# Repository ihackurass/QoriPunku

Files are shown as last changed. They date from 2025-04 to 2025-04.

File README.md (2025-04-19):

# QoriPunku (SecureGate)


[]()

## Visión General

**QoriPunku** ("Puerta de Oro" en quechua) es un sistema de control de acceso inteligente que combina tecnología RFID con verificación remota mediante fotografías. Diseñado para mejorar la seguridad en puntos de acceso, permite la autenticación rápida de usuarios registrados y ofrece una segunda capa de verificación por administrador para visitantes no registrados.

## Características Principales

- **Autenticación RFID**: Identificación rápida mediante tarjetas autorizadas
- **Sistema de respaldo fotográfico**: Captura imágenes de visitantes no autorizados
- **Verificación remota**: Envío de fotografías al administrador vía WhatsApp
- **Control de acceso dual**: RFID para usuarios regulares, aprobación administrativa para visitantes
- **Panel administrativo**: Configuración de parámetros del sistema mediante contraseña
- **Acceso automático**: Apertura de puerta mediante servomotor

## Componentes de Hardware

<div align="center">
  
  
  
  
  
  
  
  
</div>

## Diagrama del Sistema

<div align="center">
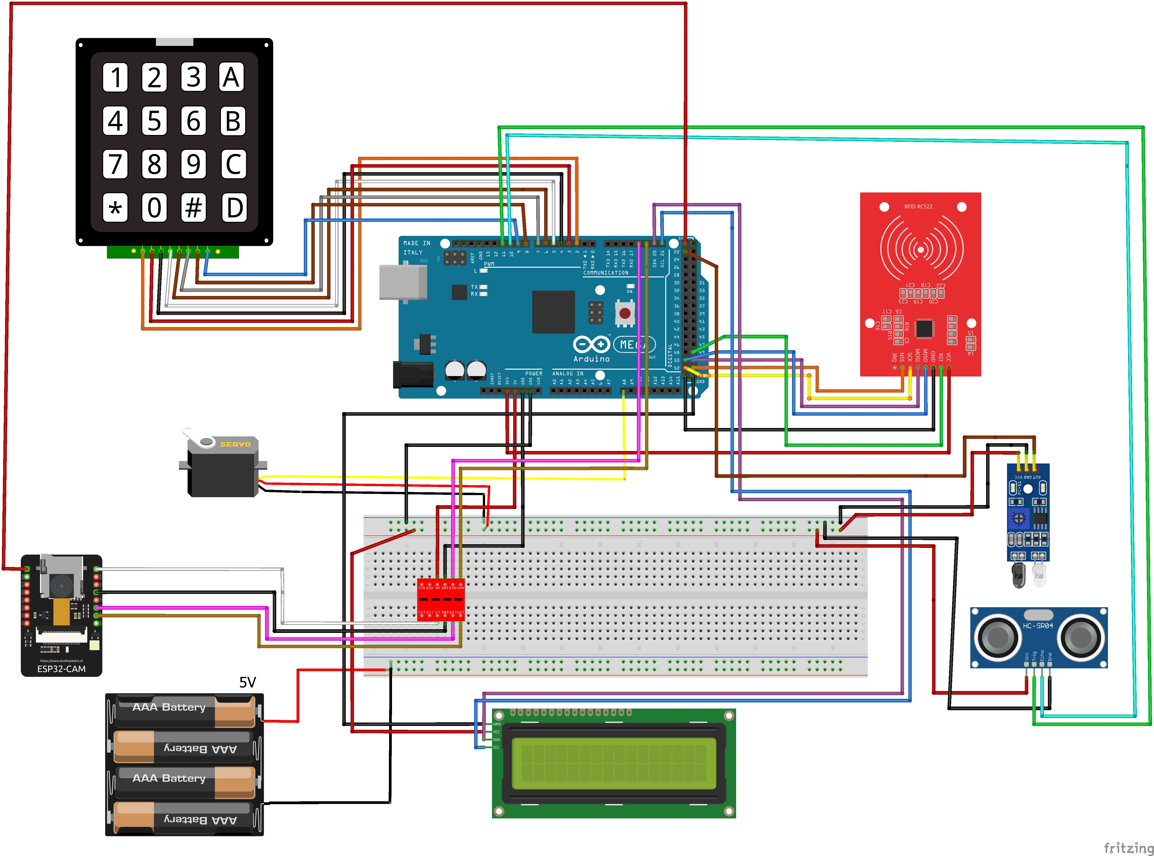
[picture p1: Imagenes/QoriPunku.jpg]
Diagrama de conexiones
  
</div>

## Flujo de Funcionamiento

### Acceso con Tarjeta Registrada
1. Usuario presenta la tarjeta RFID al lector
2. El sistema valida el UUID contra la base de datos
3. Si está registrado, el servomotor activa la apertura de la puerta
4. La pantalla LCD muestra mensaje de "Acceso concedido"

### Acceso con Tarjeta No Registrada
1. Usuario presenta la tarjeta RFID no reconocida
2. El sistema detecta la presencia del usuario con sensores ultrasónico e infrarrojo
3. ESP32-CAM captura una fotografía del visitante
4. La imagen se envía al servidor
5. El servidor procesa la imagen y envía un mensaje de WhatsApp al administrador incluyendo:
   - La fotografía del visitante
   - Opciones para aprobar o denegar el acceso
6. El administrador responde por WhatsApp ("si" o "no")
7. El servidor recibe la respuesta y la comunica al sistema
8. Si se aprueba, se abre la puerta
9. Si se deniega, se muestra mensaje de "Acceso denegado" en el LCD

### Modo Configuración
1. Introducir el código de 5 dígitos en el teclado matricial
2. Acceder al menú de opciones:
   - Cambiar número de teléfono del administrador
   - Ajustar distancia de detección del sensor
   - Cambiar contraseña de administrador
   - Salir del modo configuración

## Panel de Configuración

El sistema cuenta con un panel de configuración protegido por contraseña que permite:

- **Gestión de contacto**: Actualizar el número de teléfono del administrador para las notificaciones de WhatsApp
- **Ajuste de sensores**: Modificar la distancia de activación del sensor ultrasónico
- **Seguridad**: Cambiar la contraseña de acceso al panel de configuración

## Capturas

<div align="center">
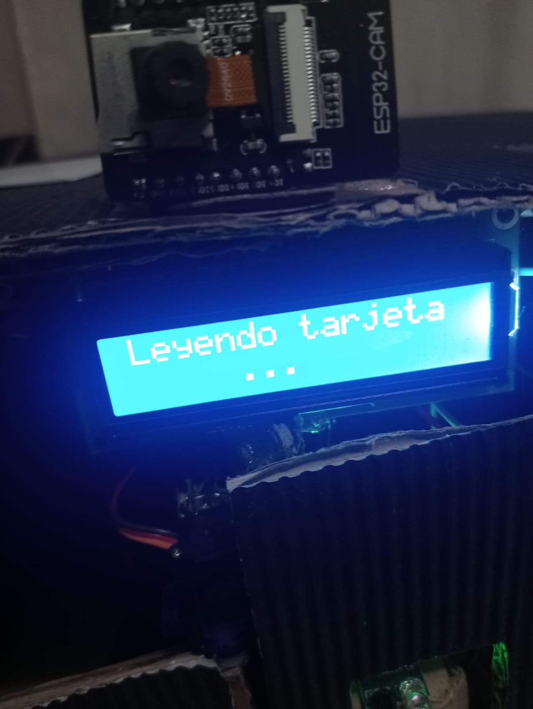
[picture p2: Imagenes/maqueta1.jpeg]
Maqueta
  
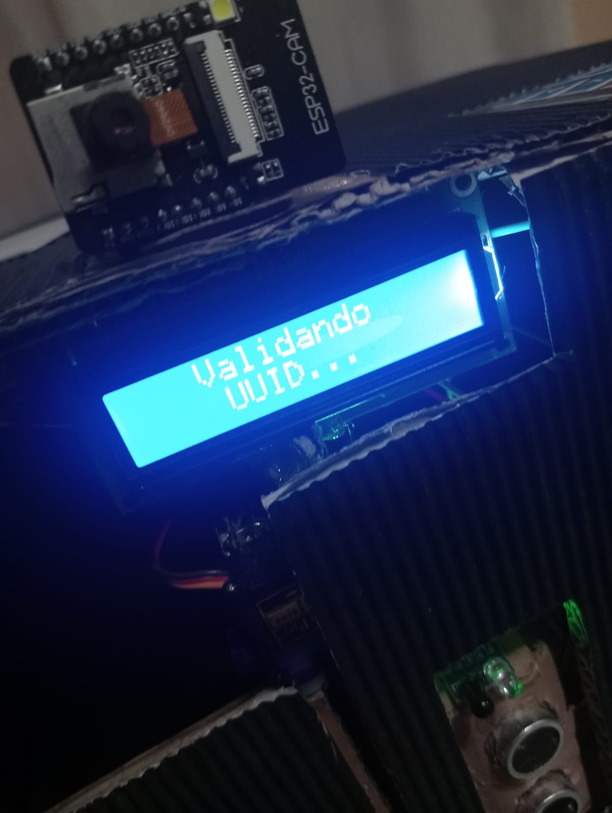
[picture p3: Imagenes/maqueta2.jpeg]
Maqueta 2
  
</div>

<div align="center">
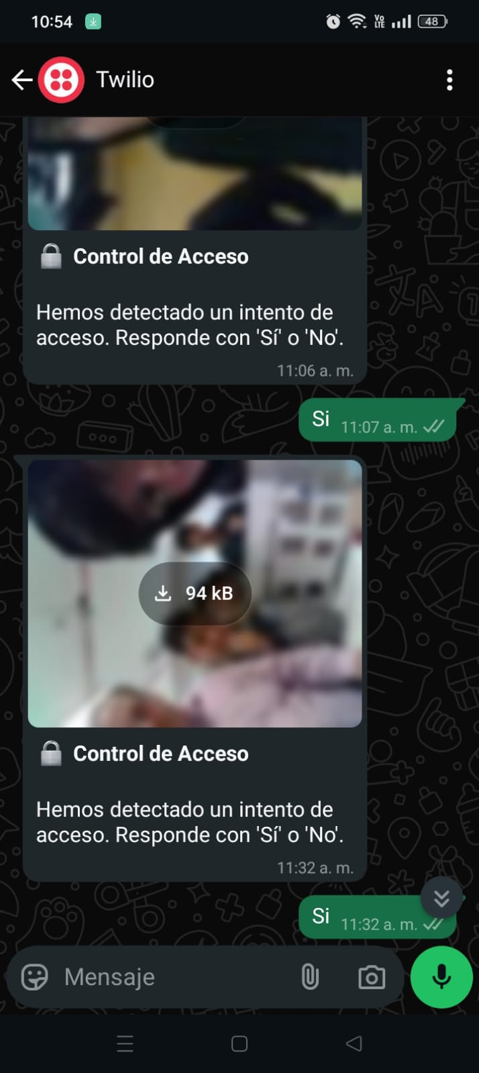
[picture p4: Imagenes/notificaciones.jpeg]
Notificaciones
  
</div>

## Arquitectura del Sistema

El sistema está dividido en tres componentes principales:

### Unidad de Control
- Maneja el lector RFID, pantalla LCD, teclado y servomotor
- Controla los sensores de presencia (ultrasónico e infrarrojo)
- Proporciona interfaz de usuario mediante LCD y teclado
- Gestiona el menú de configuración y validación de entradas

### Unidad de Cámara
- Captura fotografías de alta calidad
- Establece comunicación WiFi con el servidor
- Envía imágenes capturadas al servidor
- Recibe respuestas del servidor sobre el acceso

### Servidor
- Almacena datos de usuarios registrados y configuraciones
- Procesa las imágenes recibidas desde la unidad de cámara
- Envía mensajes de WhatsApp al administrador con la fotografía del visitante
- Recibe y procesa respuestas del administrador
- Comunica decisiones de acceso de vuelta al sistema

## Requisitos de Hardware

- Arduino Mega 2560
- Módulo ESP32-CAM
- Lector RFID RC522
- Pantalla LCD 16x2 con I2C
- Teclado matricial 4x4
- Servomotor para control de cerradura
- Sensor ultrasónico HC-SR04
- Sensor infrarrojo
- Módulo de alimentación
- Cables y protoboard

## Instalación y Configuración

1. **Configuración del hardware**
   - Conectar todos los componentes según el diagrama proporcionado
   - Asegurar alimentación adecuada para todos los módulos

2. **Instalacion de biblioteca Twilio**
   - cd QoriPunku/
   - composer require twilio/sdk
   - composer show twilio/sdk
    
3. **Configuración del servidor**
   - Crear una carpeta `CA` en tu servidor
   - Subir los scripts de la carpeta `Web`
   - Configurar la base de datos con tus credenciales en `config.php`
   - Importar el archivo `Database/QoriPunku.sql` a tu BD
   - Configurar la API de WhatsApp (Twilio) en el script `config.php`

4. **Programación de los microcontroladores**
   - Cargar el firmware en Arduino Mega
   - Cargar el firmware en ESP32-CAM
   - Configurar las credenciales WiFi y URL del servidor

## Aplicaciones

- Control de acceso en oficinas y edificios corporativos
- Seguridad en laboratorios y áreas restringidas
- Control de entrada en condominios y urbanizaciones
- Acceso a zonas sensibles con supervisión administrativa
- Registro de visitantes en instituciones

## Licencia

Este proyecto está bajo la Licencia MIT - consulta el archivo [LICENSE](LICENSE.md) para más detalles.

## Contacto

Si tienes preguntas o sugerencias, no dudes en contactarme :)

---

<div align="center">
  <sub>Desarrollado con orgullo en Perú, combinando tradición y tecnología.</sub>
</div>

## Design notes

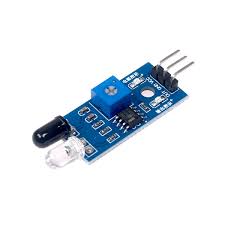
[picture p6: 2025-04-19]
Imagenes/infrarrojo.jpg

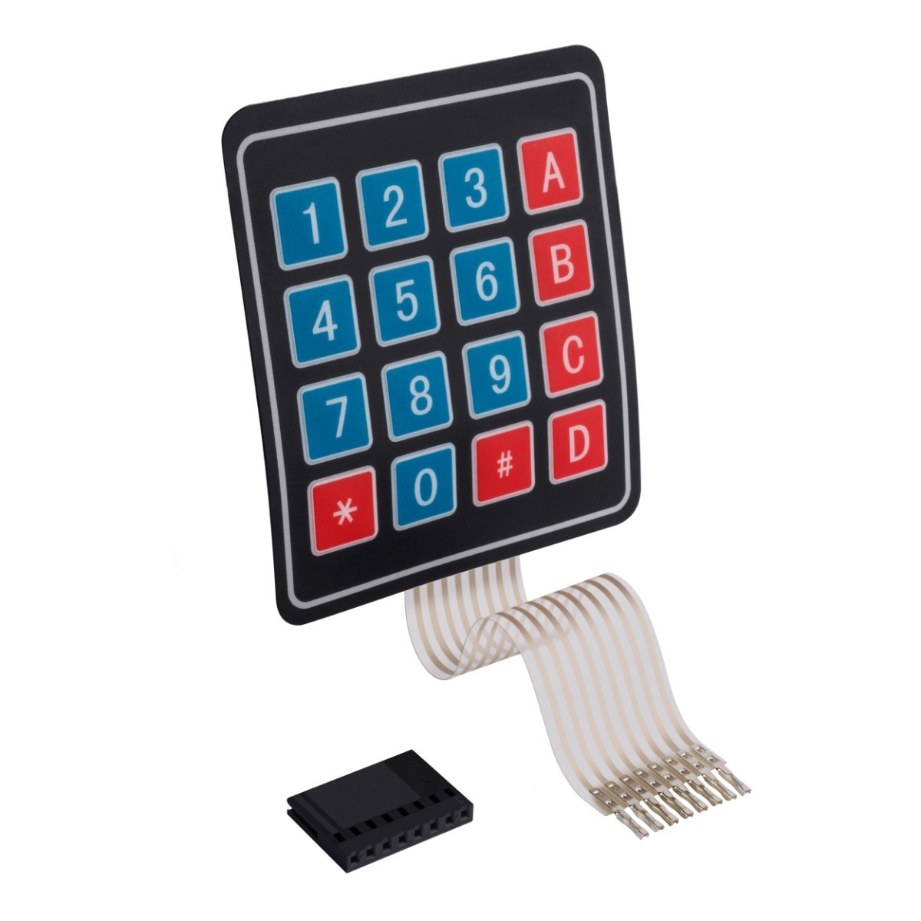
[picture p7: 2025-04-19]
Imagenes/teclado.jpg

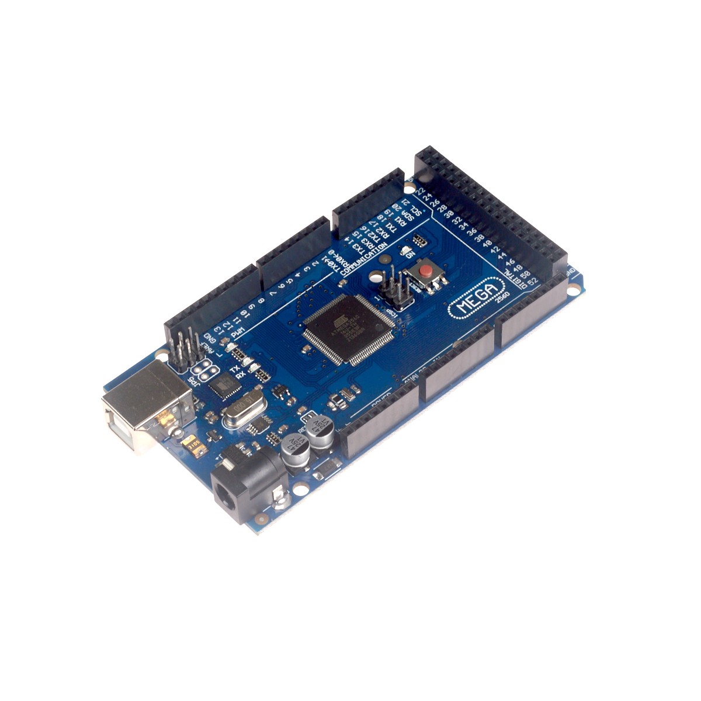
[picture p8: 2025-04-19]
Imagenes/arduino_mega.jpg

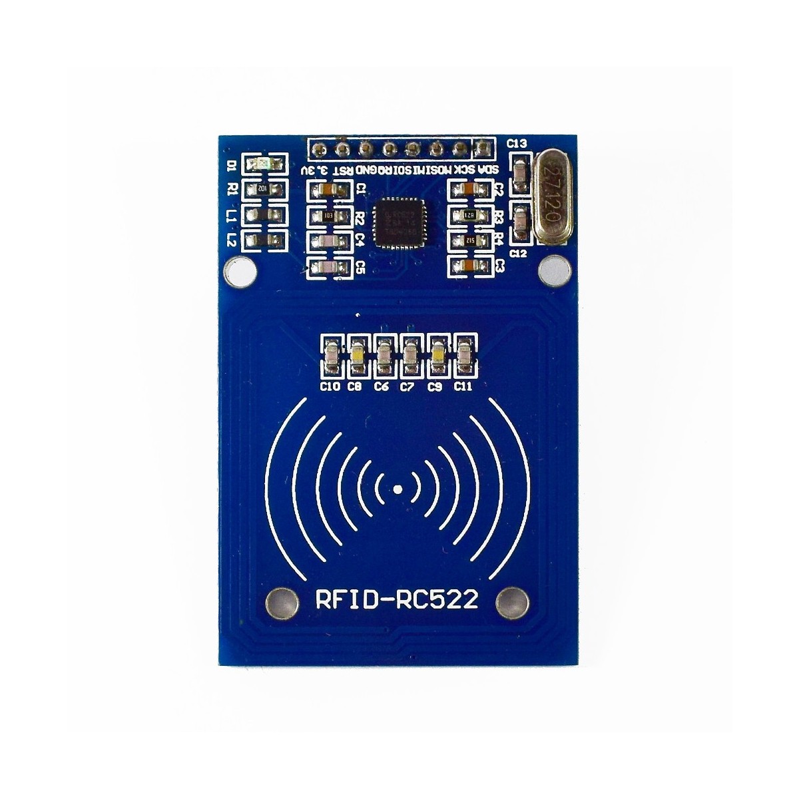
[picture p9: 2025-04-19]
Imagenes/RC522.jpg

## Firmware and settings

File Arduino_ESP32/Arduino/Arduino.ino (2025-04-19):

#include <Wire.h>
#include <SPI.h>
#include <MFRC522.h>
#include <LCDI2C_Generic.h>
#include <Keypad.h>
#include <Servo.h>

Servo miServo;  // Crea un objeto servo para controlar un servomotor

// Configuración del teclado matricial
const byte FILAS = 4; 
const byte COLUMNAS = 4; 

char keys[FILAS][COLUMNAS] = {
  {'1','2','3','A'},
  {'4','5','6','B'},
  {'7','8','9','C'},
  {'*','0','#','D'}
};

byte pinesFilas[FILAS] = {6, 7, 8, 9};
byte pinesColumnas[COLUMNAS] = {2, 3, 4, 5};  

Keypad teclado = Keypad(makeKeymap(keys), pinesColumnas, pinesFilas, COLUMNAS, FILAS);

// Configuración del RC522 y LCD
#define SS_PIN 53
#define RST_PIN 49
MFRC522 rfid(SS_PIN, RST_PIN);
LCDI2C_Generic lcd(0x27, 16, 2); // Dirección I2C de la pantalla LCD

// Pines para el sensor ultrasónico
#define TRIG_PIN 11
#define ECHO_PIN 10
// Pin para el sensor infrarrojo
#define IR_SENSOR_PIN 22

#define SERVO_PIN A8

int distanciaSensor = 50;  

String claveIngresada = "";

bool modoConfiguracion = false;

int language = 0;
String messages[2][3] = {
  {"Acceso concedido", "Acceso denegado", "Bienvenido!"},
  {"Access granted", "Access denied", "Welcome!"}
};

void setup() {
  Serial.begin(115200);    // Comunicación con la computadora
  Serial1.begin(115200);   // Comunicación Serial1 con el ESP32-CAM
  SPI.begin();
  rfid.PCD_Init();
  lcd.init();
  lcd.backlight();
  lcd.clear();
  
  miServo.attach(SERVO_PIN);

  pinMode(TRIG_PIN, OUTPUT);
  pinMode(ECHO_PIN, INPUT);
  pinMode(IR_SENSOR_PIN, INPUT);
  
  lcd.setCursor(2, 0);
  lcd.print("Bienvenido.");
  lcd.setCursor(0, 1);
  lcd.print("Ingrese IDCard..");
  delay(2000);
}

// ESPERA FOTO + ACCESO
bool esperandoFotoAcceso = false;
unsigned long tiempoInicioEspera;
const unsigned long tiempoEsperaMax = 120000; // 120 segundos

void loop() {
  if (Serial1.available()) {
    String mensajeESP32 = Serial1.readStringUntil('\n');
    if (mensajeESP32.indexOf("Foto: OK") >= 0) {
      Serial.println(mensajeESP32);
      Serial.println("Foto: OK.");
      lcd.setCursor(3, 1);
      lcd.print("Foto OK ");
      esperandoFotoAcceso = true;
      delay(2000);
    }else if (mensajeESP32.indexOf("Autorizando") >= 0) {
      lcd.clear();
      Serial.println("Verificando acceso...");
      lcd.setCursor(1, 0);
      lcd.print("Autorizando...");
      delay(2000);
    }else if (mensajeESP32.indexOf("APermitido") >= 0) {
      Serial.println("Acceso Permitido.");
      lcd.setCursor(1, 1);
      lcd.print("A. Concedido");
      esperandoFotoAcceso = false;
      miServo.write(20);
      delay(10000);
      miServo.write(90);
      lcd.clear();
    } else if (mensajeESP32.indexOf("ADenegado") >= 0) {
      Serial.println("Acceso Denegado.");
      lcd.setCursor(1, 1);
      lcd.print("A. Denegado");
      esperandoFotoAcceso = false;
      delay(2000);
      lcd.clear();
    } else if (mensajeESP32.indexOf("Foto: Error") >= 0) {
      Serial.println("Error al enviar foto.");
      lcd.setCursor(2, 1);
      lcd.print("Error Foto");
      esperandoFotoAcceso = false;
      delay(2000);
      lcd.clear();
    }

    // Opcional: Leer desde el monitor serie y enviar al ESP32-CAM
    if (Serial.available()) {
        String mensajePC = Serial.readStringUntil('\n');
        Serial1.println(mensajePC);  // Envía el mensaje al ESP32-CAM
    }

  }

  verificarModoConfiguracion();

  if (modoConfiguracion) {
    mostrarOpciones();
  } else if (!esperandoFotoAcceso) {
    
    lcd.setCursor(2, 0);
    lcd.print("Bienvenido.");
    lcd.setCursor(0, 1);
    lcd.print("Ingrese IDCard..");

    if (!rfid.PICC_IsNewCardPresent() || !rfid.PICC_ReadCardSerial()) {
      return;
    }

    lcd.clear();
    lcd.setCursor(0, 0);
    lcd.print("Leyendo tarjeta");
    lcd.setCursor(5, 1);
    lcd.print("...");
    delay(3000);

    String readUIDStr = convertUIDToString(rfid.uid.uidByte, rfid.uid.size);

    long distance = getUltrasonicDistance();
    
    if ( verificarTarjetaUUID(readUIDStr) == "I") {
      lcd.clear();
      lcd.setCursor(0, 0);
      lcd.print(messages[language][1]); // Acceso denegado
      delay(2000);

      // Verifica si hay un objeto
      if (distance < distanciaSensor) { 
        Serial.print("Objeto detectado a ");
        Serial.print(distance);
        Serial.println(" cm");

        // Verifica el sensor infrarrojo
        bool isObjectDetected = digitalRead(IR_SENSOR_PIN) == LOW;
        if (isObjectDetected) {
          lcd.clear();
          lcd.setCursor(0, 0);
          lcd.print("Tomando foto...");
          Serial1.print("1"); // Envía el comando para capturar foto al ESP32-CAM
          
          esperandoFotoAcceso = true;
          tiempoInicioEspera = millis();
        } else {
          lcd.clear();
          lcd.setCursor(2, 0);
          lcd.print("Sensor IR: ");
          lcd.setCursor(1, 1);
          lcd.print("Sin deteccion");
          delay(3000);
          lcd.clear();
        }
      } else {
        lcd.clear();
        lcd.setCursor(2, 0);
        lcd.print("Sensor US: ");
        lcd.setCursor(1, 1);
        lcd.print("Sin deteccion");
        delay(3000);
        lcd.clear();
      }
      
      Serial.print("Acceso denegado -> UID: ");
      Serial.println(readUIDStr); // Imprime el UID en el monitor serie
    } else if (verificarTarjetaUUID(readUIDStr) == "A") {
      lcd.clear();
      lcd.setCursor(0, 0);
      lcd.print(messages[language][0]); // Acceso concedido
      miServo.write(20);
      delay(10000);
      miServo.write(90);
      delay(3000);
      lcd.clear();
    }

    //delay(3000);
    //lcd.clear();

    rfid.PICC_HaltA();
  }

  // Verifica si el tiempo de espera ha excedido el límite de 10 segundos
  if (esperandoFotoAcceso && (millis() - tiempoInicioEspera >= tiempoEsperaMax)) {
    Serial.println("FotoAcceso: Tiempo de espera agotado");
    lcd.setCursor(3, 1);
    lcd.print("Sin respuesta");
    delay(3000);
    esperandoFotoAcceso = false;  // Termina la espera después del tiempo límite
    lcd.clear();
  }
}


// ESPERA CONTRASEÑA
unsigned long tiempoInicioUUIDEspera;
const unsigned long tiempoEsperaUUIDMax = 20000; // 20 segundos

String verificarTarjetaUUID(String uuidIngresado) {
    String validarBool = "";
    bool responseUUID = false;

    if (uuidIngresado.length() > 0) {
        //Serial.println("UUID leído: " + uuidIngresado);
        lcd.clear();
        lcd.setCursor(3, 0);
        lcd.print("Validando");
        lcd.setCursor(4, 1);
        lcd.print("UUID...");
        delay(2000);

        // Enviar UUID al ESP32-CAM para validación
        Serial1.println("5:" + uuidIngresado);
        unsigned long tiempoInicioUUIDEspera = millis();

        while (millis() - tiempoInicioUUIDEspera < tiempoEsperaUUIDMax) {  // 20 segundos de espera
            if (Serial1.available()) {
                String validarmensajeUUID = Serial1.readStringUntil('\n');
                if (validarmensajeUUID.indexOf("UUID válido") >= 0) {
                    //Serial.println("UUID: OK");
                    responseUUID = true;
                    validarBool = "A";
                    lcd.clear();
                    break;
                } else if (validarmensajeUUID.indexOf("UUID inválido") >= 0) {
                    //Serial.println("UUID inválido");
                    responseUUID = true;
                    validarBool = "I";
                    lcd.clear();
                    break;
                }
            }
        }

        if (!responseUUID && validarBool == "") {
          Serial.println("UUID: Tiempo de espera agotado");
          lcd.clear();
          lcd.setCursor(3, 0);
          lcd.print("Error");
          lcd.setCursor(2, 1);
          lcd.print("Sin respuesta");
          delay(3000);
          validarBool = "SR";
          lcd.clear();  // Limpia el LCD al finalizar
        }

    }

    return validarBool;
}

// ESPERA CONTRASEÑA
unsigned long tiempoInicioValidarEspera;
const unsigned long tiempoEsperaValidarMax = 20000; // 20 segundos

void verificarModoConfiguracion() {
    bool responseValidar = false;
    char tecla = teclado.getKey();
    if (tecla) {
      claveIngresada += tecla;   
      if (claveIngresada.length() == 5) {
        lcd.clear();
        lcd.setCursor(1, 0);
        lcd.print("Verificando...");
        delay(2000);
        Serial1.println("4:"+claveIngresada);
        tiempoInicioValidarEspera = millis();
        while (millis() - tiempoInicioValidarEspera < tiempoEsperaValidarMax) {
            if (Serial1.available()) {
                String validarmensajeContrasena = Serial1.readStringUntil('\n');
                if (validarmensajeContrasena.indexOf("ValidarPassword: OK") >= 0) {
                    Serial.println("Validar Password OK");
                    modoConfiguracion = true;
                    responseValidar = true;
                    lcd.clear();
                    lcd.setCursor(4, 0);
                    lcd.print("Config");
                    lcd.setCursor(5, 1);
                    lcd.print("Mode");
                    delay(2000);
                    claveIngresada = "";
                    break;
                } else if (validarmensajeContrasena.indexOf("Contraseña inválida") >= 0) {
                    Serial.println("Validar Password Invalido");
                    lcd.clear();
                    responseValidar = true;
                    lcd.setCursor(5, 0);
                    lcd.print("Clave");
                    lcd.setCursor(3, 1);
                    lcd.print("Incorrecta");
                    delay(2000);
                    claveIngresada = "";
                    break;
                }
            }
        }

        if (!responseValidar) {
          Serial.println("Error Validar Pass");
          lcd.clear();
          lcd.setCursor(5, 0);
          lcd.print("Error");
          lcd.setCursor(3, 1);
          lcd.print("Respuesta");
          delay(2000);
          claveIngresada = "";
          lcd.clear();
        }

      }
    } 
}

// ESPERA CONTRASEÑA

unsigned long tiempoInicioContrasenaEspera;
const unsigned long tiempoEsperaContrasenaMax = 20000; // 20 segundos

void cambiarContrasena() {
  bool esperandoContrasena = false;
  bool responseContrasena = false;
  lcd.clear();
  lcd.print("Nueva Pass:");
  String nuevaContrasena = "";
  while (true) {
    if (Serial1.available()) {
      String mensajeContrasena = Serial1.readStringUntil('\n');
      if (mensajeContrasena.indexOf("Password: OK") >= 0) {
        Serial.println("Contraseña Actualizada Correctamente");
        lcd.setCursor(1, 0);
        lcd.print("P. Actualizado");
        esperandoContrasena = false;
        responseContrasena = true;
        delay(2000);
        lcd.clear();
      } else if (mensajeContrasena.indexOf("Password: Error") >= 0) {
        Serial.println("Error Actualizacion Pass");
        lcd.setCursor(1, 1);
        lcd.print("Pass Error");
        esperandoContrasena = false;
        responseContrasena = true;
        delay(2000);
        lcd.clear();
      }
    }

    if (!esperandoContrasena) {
      if (responseContrasena) {
        responseContrasena = false;
        return;
      }
      char tecla = teclado.getKey();
      if (tecla) {
        if (tecla == '#') {  // Confirmar nueva contraseña
          if (nuevaContrasena.length() == 5) {
            lcd.clear();
            lcd.print("Confirmar Pass:");
            String confirmarContrasena = leerContrasena();
            if (nuevaContrasena == confirmarContrasena) {
              lcd.clear();
              lcd.setCursor(1, 0);
              lcd.print("Actualizando...");
              Serial1.print("3:" + nuevaContrasena);  // Comando para actualizar contraseña
              tiempoInicioContrasenaEspera = millis();
              esperandoContrasena = true;
            } else {
              lcd.clear();
              lcd.print("No coinciden!");
              delay(2000);
              lcd.clear();
              lcd.print("Nueva Pass:");
              nuevaContrasena = "";  // Reiniciar si no coincide
            }
          } else {
            lcd.clear();
            lcd.print("Nueva Pass:");
            nuevaContrasena = "";  // Reiniciar si menos de 5 caracteres
          }
        } else if (tecla == '*') {  // Borrar último dígito
          if (nuevaContrasena.length() > 0) {
            nuevaContrasena.remove(nuevaContrasena.length() - 1);
            lcd.setCursor(0, 1);
            lcd.print(nuevaContrasena + " ");
          }
        } else if (tecla == 'C') {  // Cancelar operación
          lcd.clear();
          lcd.setCursor(3, 0);
          lcd.print("Cancelado");
          delay(2000);
          return;
        } else if (tecla >= '0' && tecla <= '9') {  // Solo aceptar dígitos
          if (nuevaContrasena.length() < 9) {  // Limitar longitud máxima de la contraseña
            nuevaContrasena += tecla;
            lcd.setCursor(0, 1);
            lcd.print(nuevaContrasena);
          }
        }
      }
    } else {
      if (esperandoContrasena && (millis() - tiempoInicioContrasenaEspera >= tiempoEsperaContrasenaMax)) {
        Serial.println("Pass: Tiempo de espera agotado");
        lcd.setCursor(1, 1);
        lcd.print("Sin respuesta");
        delay(3000);
        esperandoContrasena = false;  // Termina la espera después del tiempo límite
        responseContrasena = true;
        lcd.clear();
      }
    }
  }
}

String leerContrasena() {
  String contrasena = "";
  while (true) {
    char tecla = teclado.getKey();
    if (tecla) {
      if (tecla == '#') {
        return contrasena;
      } else if (tecla == '*') {
        if (contrasena.length() > 0) {
          contrasena.remove(contrasena.length() - 1);
          lcd.setCursor(0, 1);
          lcd.print(contrasena + " ");
        }
      } else if (tecla >= '0' && tecla <= '9') {
        if (contrasena.length() < 9) {  // Limitar longitud máxima de la contraseña
          contrasena += tecla;
          lcd.setCursor(0, 1);
          lcd.print(contrasena);
        }
      }
    }
  }
}

const int numOpciones = 4;
String opcionesMenu[] = {
  "1: Cambiar Num",
  "2: Distancia",
  "3: Cambiar Pass",
  "4: Salir"
};

int opcionSeleccionada = 0;

void mostrarOpciones() {
  lcd.clear();
  mostrarOpcionActual();  // Muestra las opciones iniciales

  while (true) {
    char tecla = teclado.getKey();

    if (tecla) {
      if (tecla == 'A') {  // Tecla para subir
        if (opcionSeleccionada > 0) {
          opcionSeleccionada--;
          mostrarOpcionActual();
        }
      } else if (tecla == 'B') {  // Tecla para bajar
        if (opcionSeleccionada < numOpciones - 1) {
          opcionSeleccionada++;
          mostrarOpcionActual();
        }
      } else if (tecla >= '1' && tecla <= '4') {  // Selección directa por número
        int opcion = tecla - '1';  // Convierte char a int
        ejecutarOpcion(opcion);
        break;
      }
    }
  }
}

void mostrarOpcionActual() {
  lcd.clear();
  lcd.print(opcionesMenu[opcionSeleccionada]);
  if (opcionSeleccionada < numOpciones - 1) {
    lcd.setCursor(0, 1);
    lcd.print(opcionesMenu[opcionSeleccionada + 1]);
  }
}

void ejecutarOpcion(int opcion) {
  lcd.clear();
  switch (opcion) {
    case 0:
      cambiarNumeroTelefono();
      break;
    case 1:
      cambiarDistanciaSensor();
      break;
    case 2:
      // Acción para la opción tres
      cambiarContrasena();
      break;
    case 3:
      modoConfiguracion = false;
      lcd.print("Saliendo...");
      delay(2000);
      lcd.clear();
      break;
  }
}

// ESPERA NUMERO

unsigned long tiempoInicioNumeroEspera;
const unsigned long tiempoEsperaNumeroMax = 20000; // 20 segundos

// Función para cambiar el número de teléfono
void cambiarNumeroTelefono() {
  bool esperandoNumero = false;
  bool responseNumero = false;
  lcd.clear();
  lcd.print("Nuevo Numero:");
  String numeroTelefono = "";  
  while (true) {
    if (Serial1.available()) {
        String mensajeNumero = Serial1.readStringUntil('\n');  // Asegura leer hasta el fin de línea
        if (mensajeNumero.indexOf("Actualización: OK") >= 0) {
          Serial.println("Numero Actualizado Correctamente");
          lcd.setCursor(1, 1);
          lcd.print("N. Actualizado");
          esperandoNumero = false;
          responseNumero = true;
          delay(2000);
          lcd.clear();
        }
        else if (mensajeNumero.indexOf("Actualización: OK") >= 0) {
          Serial.println("Error Actualizacion Numero");
          lcd.setCursor(2, 1);
          lcd.print("N. Error");
          esperandoNumero = false;
          responseNumero = true;
          delay(2000);
          lcd.clear();
        }
    }

  // Opcional: Enviar datos desde la computadora al ESP32-CAM
    if (Serial.available()) {
      String mensajePC = Serial.readString();
      Serial1.println(mensajePC);      // Envía el mensaje de la computadora al ESP32-CAM
    }

    if (!esperandoNumero){
      if (responseNumero){
        responseNumero = false;
        return;
      }
      char tecla = teclado.getKey();
      if (tecla) {
        if (tecla == '#') {  // # para confirmar
          if (numeroTelefono.length() == 9) {
            lcd.clear();
            lcd.setCursor(1, 0);
            lcd.print("Actualizando...");
            Serial1.print("2:"+numeroTelefono);
            tiempoInicioNumeroEspera = millis();
            esperandoNumero = true;
          } else {
            // Si el número no tiene 9 dígitos, mostrar error
            lcd.clear();
            lcd.print("Numero invalido");
            delay(2000);
            lcd.clear();
            lcd.print("Nuevo Numero:");
            numeroTelefono = "";  // Reinicia la entrada del número
          }
        } else if (tecla == '*') {  // * para borrar el último dígito
          if (numeroTelefono.length() > 0) {
            numeroTelefono.remove(numeroTelefono.length() - 1);
            lcd.setCursor(0, 1);
            lcd.print(numeroTelefono + " ");  // Limpia el dígito borrado en el LCD
          }
        } else if (tecla == 'C') {
          lcd.clear();
          lcd.setCursor(3, 0);
          lcd.print("Cancelado");
          delay(2000);
          numeroTelefono = "";
          return;
        } else if (tecla >= '0' && tecla <= '9') {  // Solo acepta dígitos
          if (numeroTelefono.length() < 9) {
            numeroTelefono += tecla;  
            lcd.setCursor(0, 1);
            lcd.print(numeroTelefono);
          }
        }
      }
    }else{
      if (esperandoNumero && (millis() - tiempoInicioNumeroEspera >= tiempoEsperaNumeroMax)) {
        Serial.println("Numero: Tiempo de espera agotado");
        lcd.setCursor(2, 1);
        lcd.print("Sin respuesta");
        delay(3000);
        esperandoNumero = false;  // Termina la espera después del tiempo límite
        responseNumero = true;
        lcd.clear();
      }
    }
  }
}

// Función para cambiar la distancia del sensor
void cambiarDistanciaSensor() {
  lcd.clear();
  lcd.print("Nueva Dist:");

  String nuevaDistancia = "";
  while (true) {
    char tecla = teclado.getKey();
    if (tecla) {
      Serial.print("Tecla para distancia: ");
      Serial.println(tecla); // Imprime la tecla presionada en el monitor serie

      if (tecla == 'C') {  // Tecla para salir
        lcd.clear();
        lcd.setCursor(3, 0);
        lcd.print("Cancelado");
        delay(2000);
        return;
      } else if (tecla == '#') {  // Confirmar
        if (nuevaDistancia.length() > 0) {
          distanciaSensor = nuevaDistancia.toInt();  
          lcd.clear();
          lcd.setCursor(4, 0);
          lcd.print("Distancia");
          lcd.setCursor(4, 1);
          lcd.print("Cambiada");
          delay(2000);
          lcd.clear();
          return;
        } else {
          lcd.clear();
          lcd.print("Valor invalido");
          delay(2000);
          lcd.clear();
          lcd.print("Nueva Dist:");
          nuevaDistancia = "";  // Reinicia la entrada
        }
      } else if (tecla == '*') {  // Borrar
        if (nuevaDistancia.length() > 0) {
          nuevaDistancia.remove(nuevaDistancia.length() - 1);
          lcd.setCursor(0, 1);
          lcd.print(nuevaDistancia + " ");  // Limpia el dígito borrado en el LCD
        }
      } else if (tecla >= '0' && tecla <= '9') {  // Solo acepta dígitos
        if (nuevaDistancia.length() < 3) {  // Limitar a 3 dígitos para una distancia razonable
          nuevaDistancia += tecla;  
          lcd.setCursor(0, 1);
          lcd.print(nuevaDistancia);
        }
      }
    }
  }
  lcd.clear();
}


// Función para convertir el UID a una cadena en formato hexadecimal
String convertUIDToString(byte *uid, byte uidSize) {
  String uidStr = "";
  for (byte i = 0; i < uidSize; i++) {
    if (uid[i] < 0x10) uidStr += "0"; // Añadir un '0' si el byte es menor de 16 para mantener formato hexadecimal
    uidStr += String(uid[i], HEX);     // Convertir byte a HEX y concatenar
  }
  uidStr.toUpperCase(); // Convertir a mayúsculas (opcional)
  return uidStr;
}


// Función para obtener la distancia con el sensor ultrasónico
long getUltrasonicDistance() {
  digitalWrite(TRIG_PIN, LOW);
  delayMicroseconds(2);
  digitalWrite(TRIG_PIN, HIGH);
  delayMicroseconds(10);
  digitalWrite(TRIG_PIN, LOW);

  long duration = pulseIn(ECHO_PIN, HIGH);
  long distance = duration * 0.034 / 2; // Convertir a centímetros
  return distance;
}

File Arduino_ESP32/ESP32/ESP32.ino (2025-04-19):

//>>>>>>>>>>>>>>>>>>>>>>>>>>>>>>>>>>>>>>>>>>>>>>>>>>>>>>>>>>>>>>>>>>>>>>>>>>>>>>>>>>>>>>>>> ESP32_CAM_Send_Photo_to_Server
//======================================== Including the libraries.
#include <WiFi.h>
#include "soc/soc.h"
#include "soc/rtc_cntl_reg.h"
#include "esp_camera.h"
#include <ArduinoJson.h>
#include <HTTPClient.h>
//======================================== 

//======================================== CAMERA_MODEL_AI_THINKER GPIO.
#define PWDN_GPIO_NUM     32
#define RESET_GPIO_NUM    -1
#define XCLK_GPIO_NUM      0
#define SIOD_GPIO_NUM     26
#define SIOC_GPIO_NUM     27

#define Y9_GPIO_NUM       35
#define Y8_GPIO_NUM       34
#define Y7_GPIO_NUM       39
#define Y6_GPIO_NUM       36
#define Y5_GPIO_NUM       21
#define Y4_GPIO_NUM       19
#define Y3_GPIO_NUM       18
#define Y2_GPIO_NUM        5
#define VSYNC_GPIO_NUM    25
#define HREF_GPIO_NUM     23
#define PCLK_GPIO_NUM     22
//======================================== 

// LED Flash PIN (GPIO 4)
#define FLASH_LED_PIN 4             

//========================================
const char* ssid = "MI_WIFI 2.4G"; // NOMBRE DE LA RED WIFI
const char* password = "MI_CLAVE"; // PASSWORD
//======================================== 

String serverName = "tu-dominio.com";
const int serverPort = 80;

// Variable to set capture photo with LED Flash.
// Set to "false", then the Flash LED will not light up when capturing a photo.
// Set to "true", then the Flash LED lights up when capturing a photo.
bool LED_Flash_ON = true;

WiFiClient client;


bool validarUUID(const String& uuidIngresado) {
    int maxAttempts = 3;
    int attempt = 0;
    bool success = false;

    while (attempt < maxAttempts && !success) {
        attempt++;
        Serial.println("Intento " + String(attempt) + " de validar el UUID...");

        HTTPClient http;
        http.begin("http://" + serverName + "/CA/validate_uuid_list.php");
        http.addHeader("Content-Type", "application/x-www-form-urlencoded");

        String postData = "uuid=" + uuidIngresado;
        int httpResponseCode = http.POST(postData);

        if (httpResponseCode > 0) {
            String response = http.getString();
            Serial.println("Respuesta del servidor: " + response);

            StaticJsonDocument<200> doc;
            DeserializationError error = deserializeJson(doc, response);

            if (error) {
                Serial.println("Error al parsear JSON: ");
                return false;
            }

            const char* status = doc["status"];
            if (String(status) == "valid") {
                Serial.println("UUID válido.");
                success = true;
            } else {
                Serial.println("UUID inválido.");
                return false;
            }
        } else {
            Serial.println("Error en la solicitud HTTP: " + String(httpResponseCode));
        }

        http.end();

        if (!success && attempt < maxAttempts) {
            Serial.println("Reintentando en 2 segundos...");
            delay(2000);  // Espera 2 segundos antes de reintentar
        }
    }

    return success;
}


bool validarContrasena(const String& contrasenaIngresada) {
    int maxAttempts = 3;
    int attempt = 0;
    bool success = false;

    while (attempt < maxAttempts && !success) {
        attempt++;
        Serial.println("Intento " + String(attempt) + " de validar la contraseña...");

        HTTPClient http;
        http.begin("http://" + serverName + "/CA/validate_password.php");
        http.addHeader("Content-Type", "application/x-www-form-urlencoded");

        String postData = "password=" + contrasenaIngresada;
        int httpResponseCode = http.POST(postData);

        if (httpResponseCode > 0) {
            String response = http.getString();
            Serial.println("Respuesta del servidor: " + response);

            if (response.indexOf("\"status\":\"valid\"") >= 0) {
                Serial.println("Contraseña válida.");
                success = true;
            } else {
                Serial.println("Contraseña inválida.");
                return false;
            }
        } else {
            Serial.println("Error en la solicitud HTTP: " + String(httpResponseCode));
        }

        http.end();

        if (!success && attempt < maxAttempts) {
            Serial.println("Reintentando en 2 segundos...");
            delay(2000);  // Espera 2 segundos antes de reintentar
        }
    }

    return success;
}

bool updatePassword(const String& nuevaContrasena) {
    int maxAttempts = 3;
    int attempt = 0;
    bool success = false;

    while (attempt < maxAttempts && !success) {
        attempt++;
        Serial.println("Intento " + String(attempt) + " de actualizar la contraseña...");

        HTTPClient http;
        http.begin("http://" + serverName + "/CA/update_password.php");
        http.addHeader("Content-Type", "application/x-www-form-urlencoded");

        String postData = "password=" + nuevaContrasena;
        int httpResponseCode = http.POST(postData);

        if (httpResponseCode > 0) {
            String response = http.getString();
            Serial.println("Respuesta del servidor: " + response);

            if (response.indexOf("\"status\":\"success\"") >= 0) {
                Serial.println("Contraseña actualizada correctamente.");
                success = true;
            } else {
                Serial.println("Error en la actualización de la contraseña.");
            }
        } else {
            Serial.println("Error en la solicitud HTTP: " + String(httpResponseCode));
        }

        http.end();

        if (!success && attempt < maxAttempts) {
            Serial.println("Reintentando en 2 segundos...");
            delay(2000);
        }
    }

    return success;
}
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

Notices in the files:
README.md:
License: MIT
